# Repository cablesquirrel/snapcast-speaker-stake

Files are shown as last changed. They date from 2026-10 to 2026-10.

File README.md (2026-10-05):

# Snapcast Speaker Stake

Hardware and firmware design to retrofit the [Hampton Bay B0029RA](https://www.homedepot.com/p/Hampton-Bay-16-9-in-Black-Outdoor-Landscape-Speaker-B0029RA-2/305754399) outdoor Bluetooth speaker into a [Snapcast](https://github.com/snapcast/snapcast) client.

The design uses an [ESP32-S3 (Seeed XIAO)](https://www.seeedstudio.com/XIAO-ESP32S3-p-5627.html) along with a [I2S DAC](https://www.amazon.com/dp/B08YNJGSN4) and [5-watt amplifier](https://www.amazon.com/dp/B0F6YBYMWY).

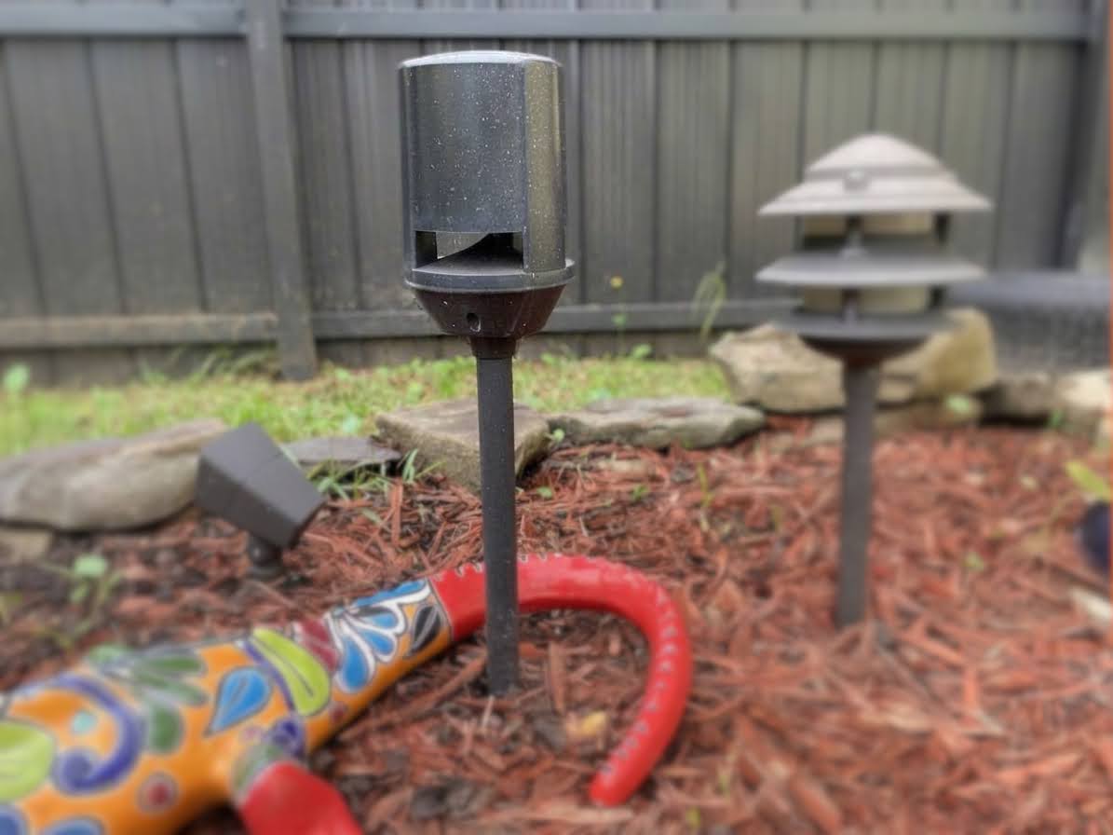
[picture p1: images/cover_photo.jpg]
Cover Photo


## 📁 Repo Layout

```
hardware/
  LICENSE          CERN-OHL-S-2.0
  libraries/       Footprint and symbol libraries used by both boards
  v1/              KiCad project and Gerbers, original 3 W design (MAX98357A)
  v2.0.1/          KiCad project and Gerbers, 5 W design (GY-PCM5102A + CH05D)
firmware/
  snapclient/      Upstream firmware (submodule, pinned to 5cda3a7)
  patches/         upstream-changes.patch: our changes to four upstream files
  overlay/         New files we add (status_led component, speaker-stake sdkconfigs)
  CHANGES.md       Every file and line changed from upstream, with rationale
scripts/
  setup-firmware.ps1  Applies the patch and overlay to firmware/snapclient
releases/
  max98357_combo/  Prebuilt flash images for the 3 W flavor
  pcm5102a_ch05d/  Prebuilt flash images for the 5 W flavor
```

## 💿 Firmware flavors

| Flavor | Hardware | Config | Release |
|---|---|---|---|
| 3 W combo | XIAO + MAX98357A | `firmware/overlay/sdkconfig.max98357_combo` | `releases/max98357_combo/` |
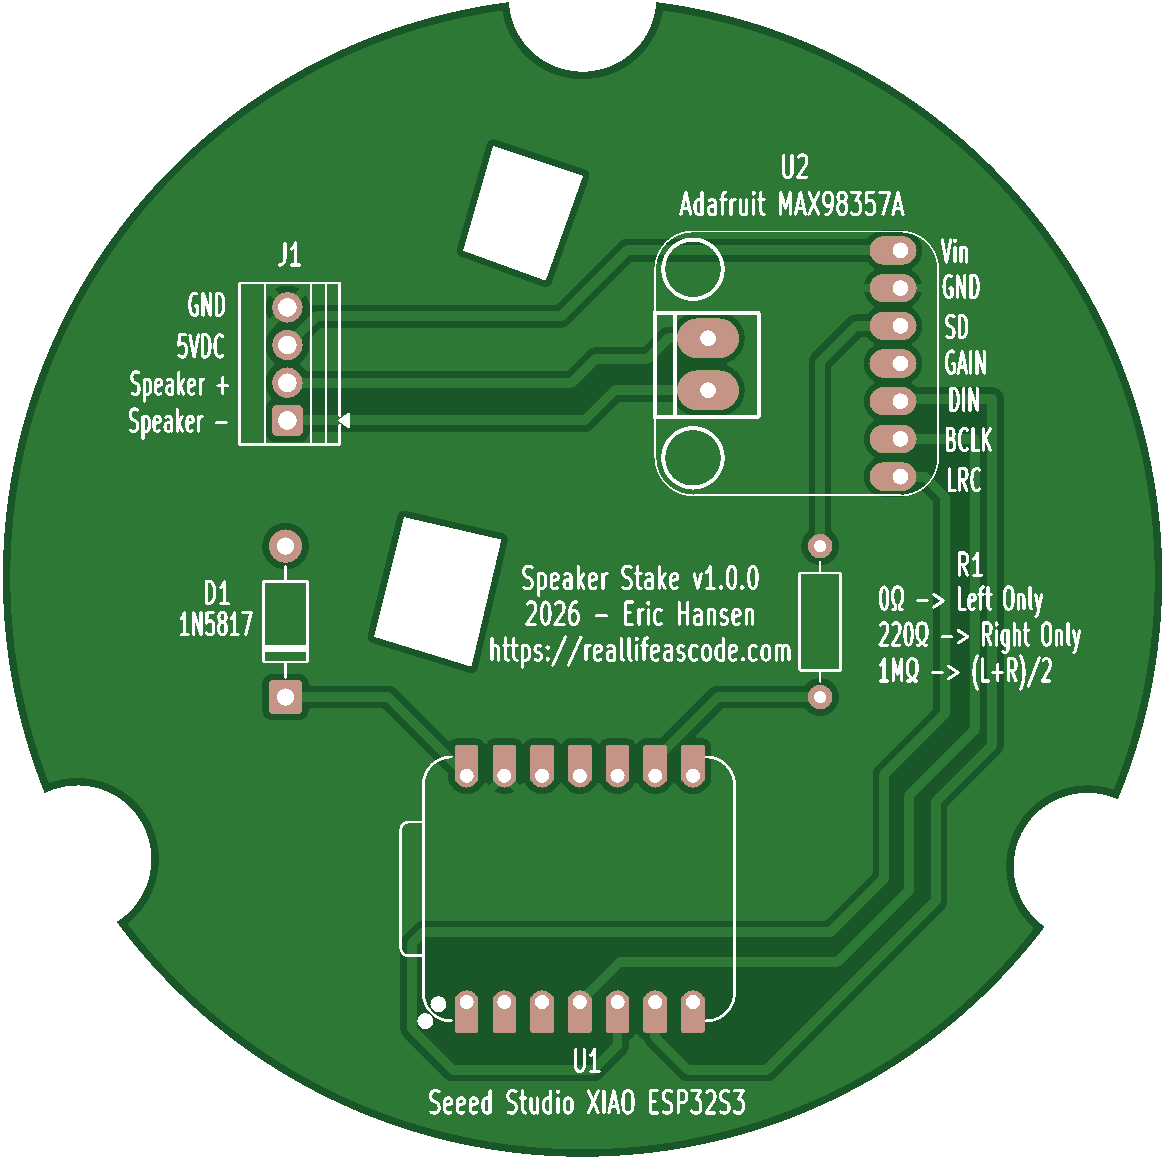
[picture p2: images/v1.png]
v1 image
|  | | | |
| 5 W separate | XIAO + GY-PCM5102A + CH05D | `firmware/overlay/sdkconfig.pcm5102a_ch05d` | `releases/pcm5102a_ch05d/` |
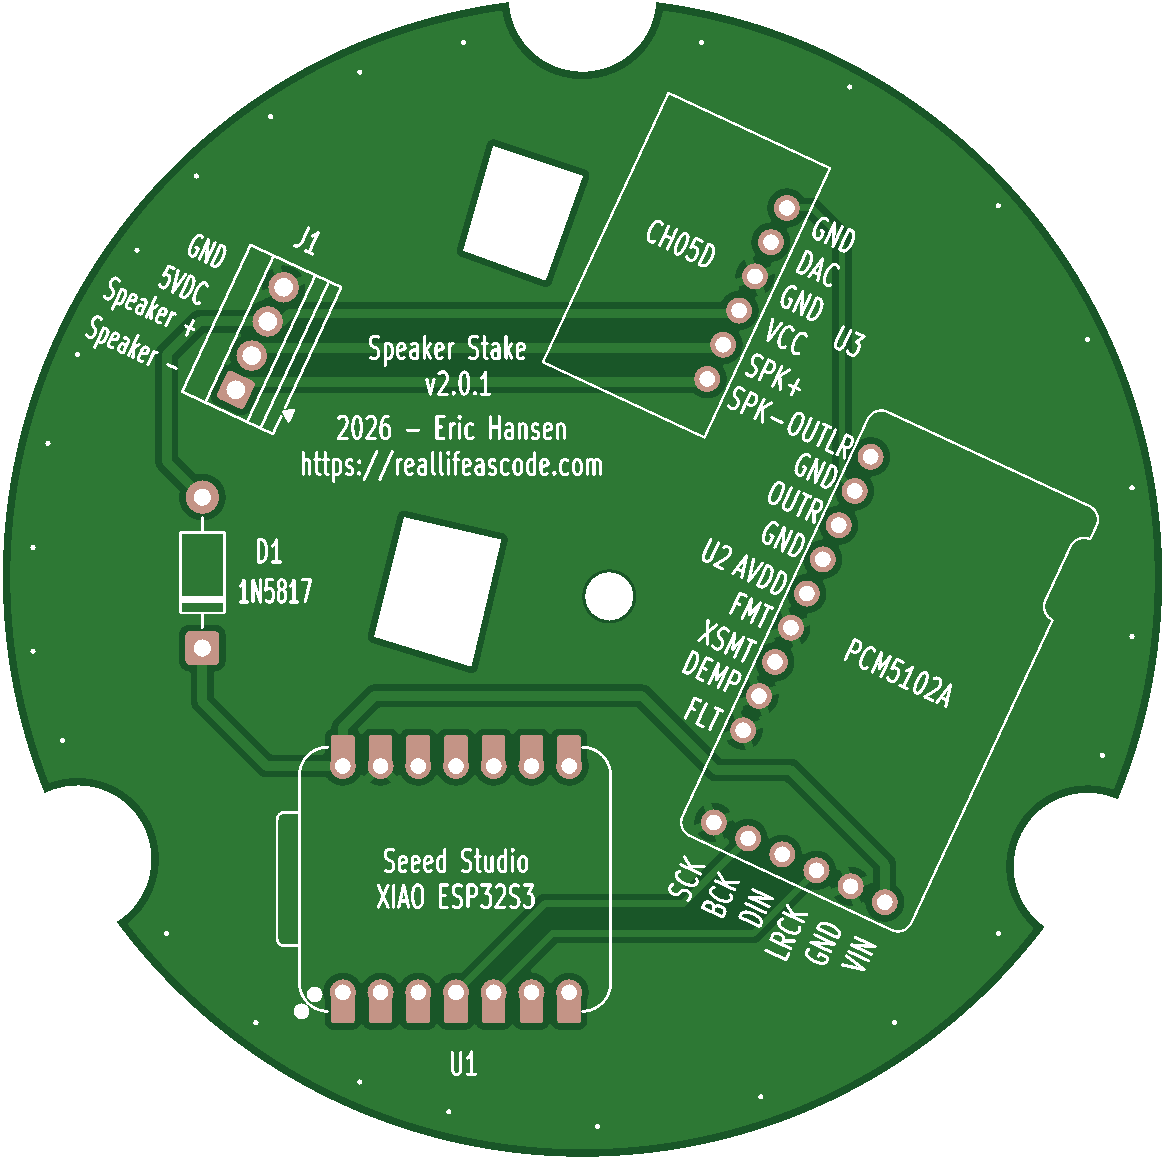
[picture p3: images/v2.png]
v2 image
|  | | | |

Both flavors are built from the same source tree. They differ only in DAC configuration. See `firmware/CHANGES.md` for the full list of changes from upstream.

## 📦 Flash a prebuilt release

Each release folder contains the four images needed for a full flash:

```
python -m esptool --chip esp32s3 -p COMx write_flash \
  0x0 bootloader.bin 0x8000 partition-table.bin 0x1d000 ota_data_initial.bin 0x20000 snapclient.bin
```

Replace `COMx` with the board's port. Run this from inside the release folder.

## 🛠 Set up ESP-IDF (Windows)

The firmware builds with ESP-IDF **v5.5.1**. Other versions are untested.

1. **Install Git for Windows** from https://git-scm.com/download/win if you don't have it.

2. **Clone ESP-IDF v5.5.1 with submodules.** This takes a while. In PowerShell:
   ```powershell
   mkdir C:\Espressif
   cd C:\Espressif
   git clone -b v5.5.1 --recursive https://github.com/espressif/esp-idf.git
   ```

3. **Install the toolchain for the ESP32-S3:**
   ```powershell
   cd C:\Espressif\esp-idf
   .\install.ps1 esp32s3
   ```
   This downloads the Xtensa compiler, CMake, Ninja, and a Python virtual environment. By default they go under `%USERPROFILE%\.espressif`. To put them elsewhere, set `IDF_TOOLS_PATH` before running the script, for example `$env:IDF_TOOLS_PATH = "C:\Espressif\tools"`.

   If PowerShell blocks the script, run `Set-ExecutionPolicy -Scope CurrentUser RemoteSigned` once and try again.

4. **Activate the environment in every new terminal.** From the `esp-idf` folder:
   ```powershell
   .\export.ps1
   ```
   If you set `IDF_TOOLS_PATH` in step 3, set it again in the terminal first.

5. **Check the install:**
   ```powershell
   idf.py --version
   ```
   It should print `ESP-IDF v5.5.1`.

6. **Connect the board.** The XIAO ESP32-S3 uses its built-in USB-C port, so no USB-serial driver is needed. If no COM port appears, try a different cable. Some cables only charge and don't carry data.

When `idf.py --version` works, continue to **Build from source** below.

## 📚 Build from source

First, clone the repo with its submodules and prepare the firmware. This only needs to be done once per clone:

```powershell
git clone --recursive https://github.com/cablesquirrel/snapcast-speaker-stake
cd snapcast-speaker-stake
.\scripts\setup-firmware.ps1
```

The script checks out upstream at the pinned commit, applies `firmware/patches/upstream-changes.patch`, and copies in the overlay files. It is safe to run again.

Requires ESP-IDF 5.5.1 (see above). Build each flavor from `firmware/snapclient` into its own directory:

```
cd firmware\snapclient
idf.py -B build -D SDKCONFIG=sdkconfig.max98357_combo build
idf.py -B build.pcm5102a_ch05d -D SDKCONFIG=sdkconfig.pcm5102a_ch05d build
```

## 📶 OTA update

With the device on the network, push a new app image to its OTA listener on port 8032. Use a direct file reference so curl sends a Content-Length header:

```
curl <device-ip>:8032 --data-binary @releases/pcm5102a_ch05d/snapclient.bin
```

The connection is reset when the transfer completes. That is expected: the device reboots into the new image.

## 📱 WiFi

WiFi credentials are not compiled in. Provision them over USB-C with Improv WiFi (for example, web.esphome.io).

## 📝 Hardware notes

- Footprint and symbol libraries used by the boards are in `hardware/libraries/`. Each project's `fp-lib-table` and `sym-lib-table` reference them with `${KIPRJMOD}/../libraries/`, so the projects open from a fresh clone. Add the libraries to your global KiCad tables only if you need them outside these projects.
- `hardware/libraries/` contains the Seeed XIAO series, GY-PCM5102A, CH05D (provisional, see its KNOWN_ISSUES), and Adafruit MAX98357A libraries as copied from the local KiCad setup.
- The V2.0.1 known issues are listed in `hardware/v2.0.1/KNOWN_ISSUES.md`. That board was sent to fab with them.

## ⚖ Licensing

- **Hardware** (`hardware/`): [CERN-OHL-S-2.0](hardware/LICENSE), the strongly reciprocal open-source hardware license. The GY-PCM5102A footprint in this project derives from a CERN-OHL-S library, and that license requires derivatives to stay under the same terms.
- **Firmware** (`firmware/`): upstream [CarlosDerSeher/snapclient](https://github.com/CarlosDerSeher/snapclient) is pulled in as a submodule under GPL-3.0 (see `firmware/snapclient/LICENSE`). Our changes are listed in `firmware/CHANGES.md`. Because they modify GPL-3.0 code, they are also GPL-3.0. The firmware overlay files (`status_led` and the sdkconfigs) are included in that same GPL-3.0 grant.
- **Third-party libraries**: the Adafruit MAX98357A library (`adafruit-MAX98357.*`) comes from [besi/kicad-adafruit-MAX98357](https://github.com/besi/kicad-adafruit-MAX98357), and the Seeed XIAO library (`Seeed_Studio_XIAO_Series.*`) comes from Seeed Studio. The Seeed library is CC-BY-SA-4.0 (see `hardware/libraries/LICENSES/`). The Adafruit library has no declared license upstream and is included as-is, pending a takedown request if the owner objects. See `hardware/libraries/README.md`.

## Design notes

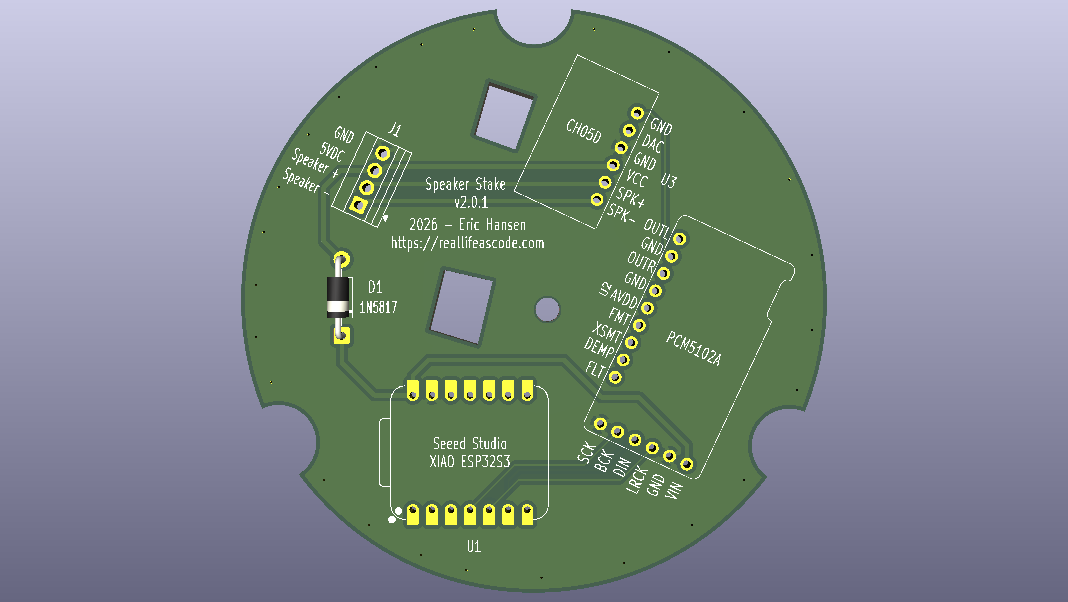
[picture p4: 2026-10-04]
hardware/v2.0.1/Speaker_Stake_v2.0.1.png

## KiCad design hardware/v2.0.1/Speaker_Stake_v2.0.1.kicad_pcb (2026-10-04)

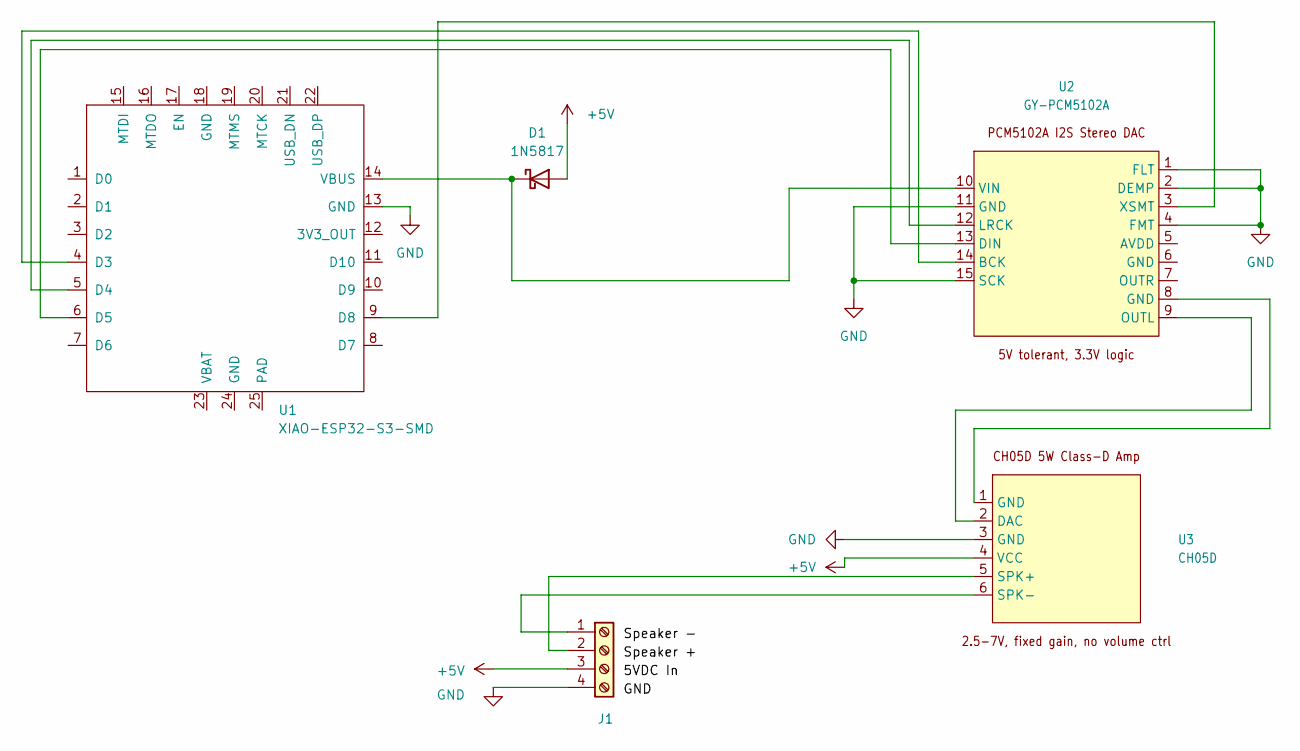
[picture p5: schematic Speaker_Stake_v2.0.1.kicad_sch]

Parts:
D1: 1N5817; D_DO-41_SOD81_P10.16mm_Horizontal
J1: Screw_Terminal_01x04; TerminalBlock_Xinya_XY308-2.54-4P_1x04_P2.54mm_Horizontal
U1: XIAO-ESP32-S3-SMD; XIAO-ESP32-S3-DIP
U2: GY-PCM5102A
U3: CH05D

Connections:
+5V: D1.2 (A), J1.3, U3.4 (VCC)
GND: J1.4, U1.13 (GND), U2.1 (FLT), U2.2 (DEMP), U2.4 (FMT), U2.11 (GND), U2.15 (SCK), U3.3 (GND)
unnamed: D1.1 (K), U1.14 (VBUS), U2.10 (VIN)
unnamed: J1.1, U3.6 (SPK-)
unnamed: J1.2, U3.5 (SPK+)
unnamed: U1.4 (D3), U2.14 (BCK)
unnamed: U1.5 (D4), U2.12 (LRCK)
unnamed: U1.6 (D5), U2.13 (DIN)
unnamed: U1.9 (D8), U2.3 (XSMT)
unnamed: U2.8 (GND), U3.1 (GND)
unnamed: U2.9 (OUTL), U3.2 (DAC)

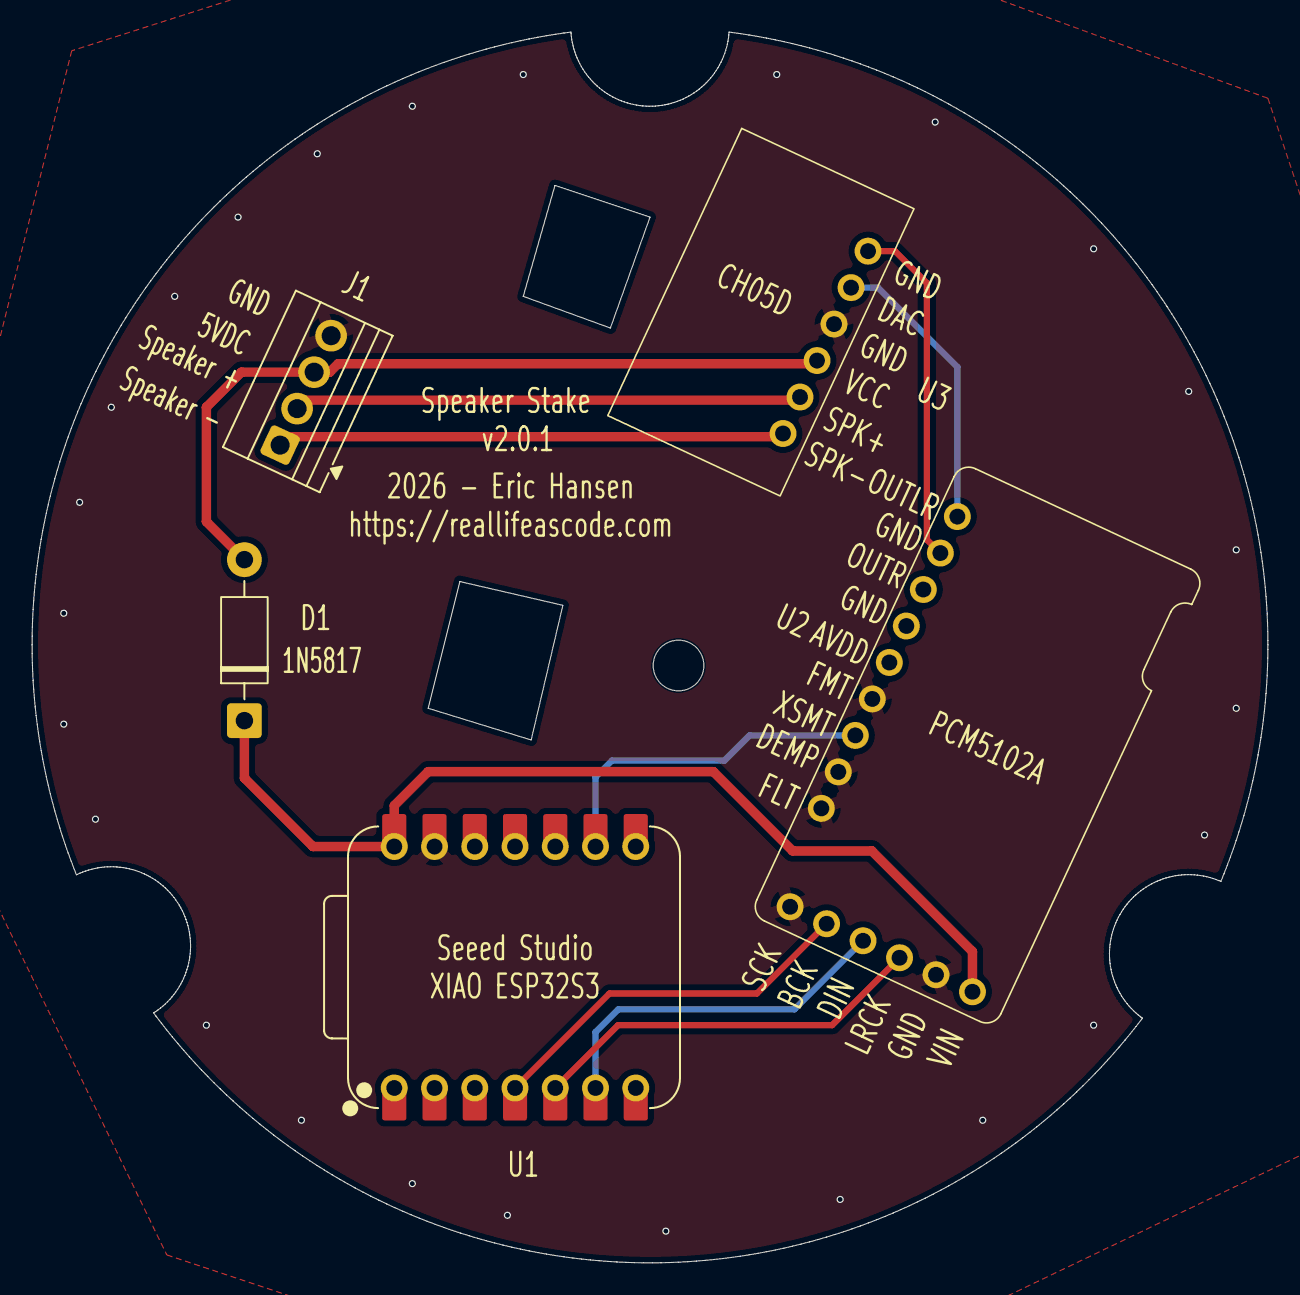
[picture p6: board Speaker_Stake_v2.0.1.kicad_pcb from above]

Board: 2 copper layers, 78.0 x 77.7 mm, 5 parts (0 on the bottom side), 11 nets.

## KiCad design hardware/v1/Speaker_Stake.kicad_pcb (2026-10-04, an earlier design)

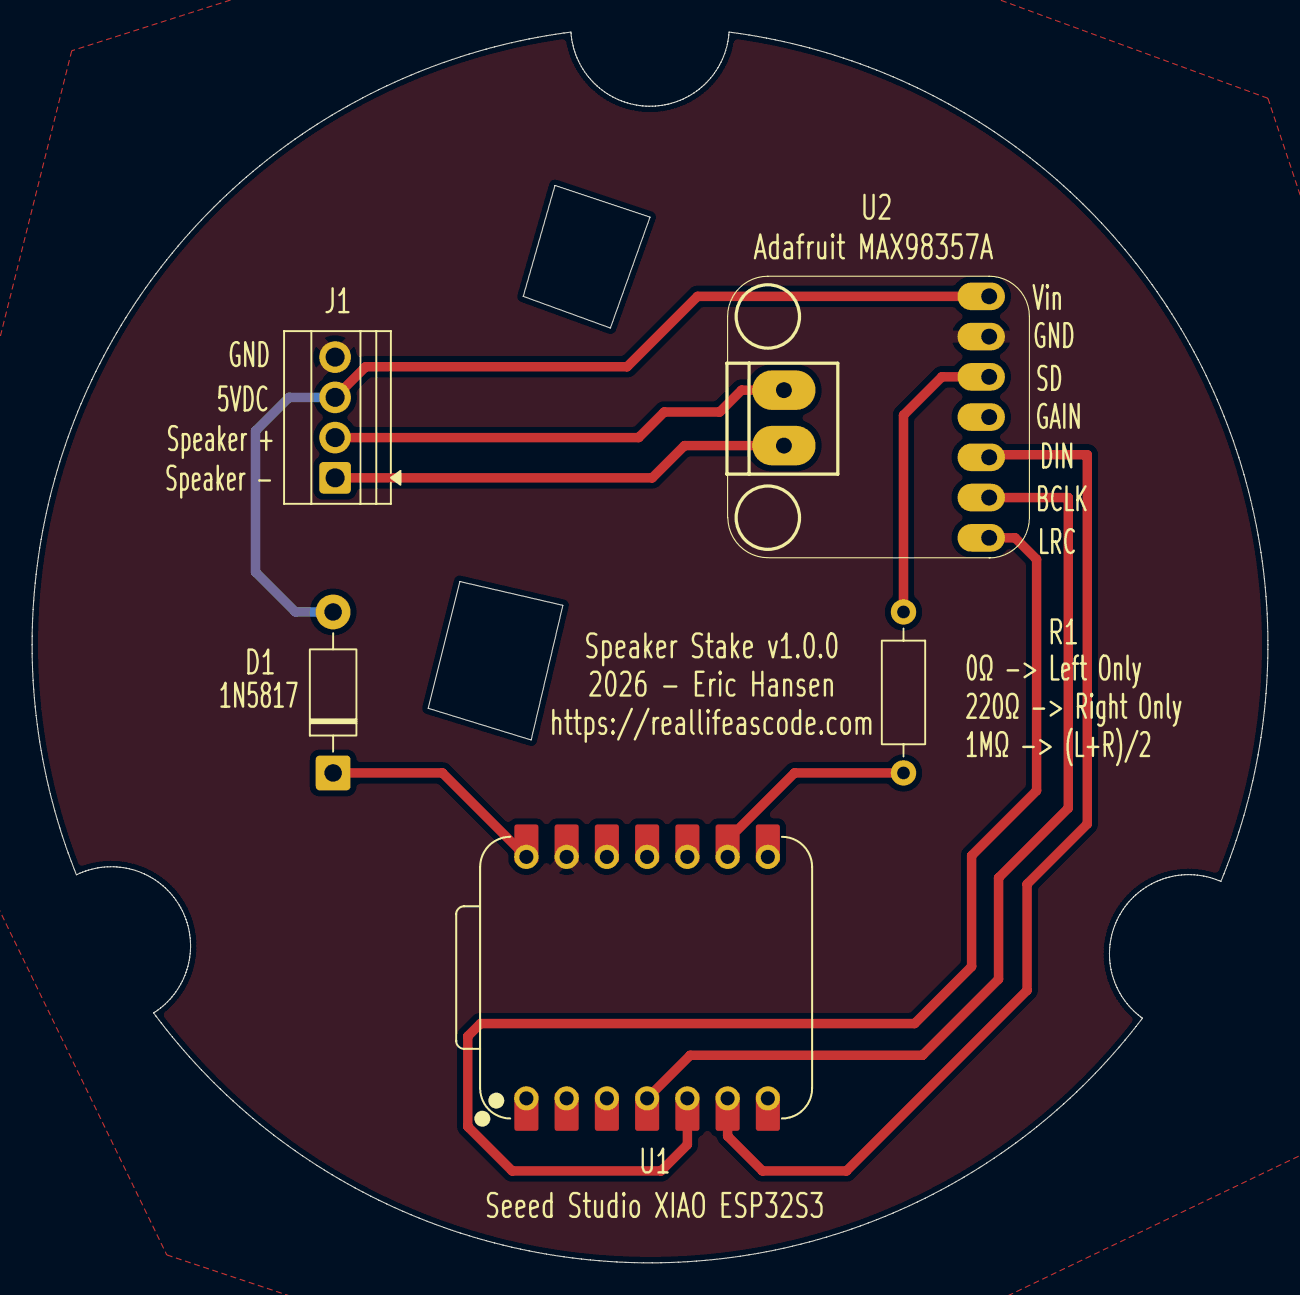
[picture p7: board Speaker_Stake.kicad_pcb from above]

Board: 2 copper layers, 78.0 x 77.7 mm, 5 parts (0 on the bottom side), 10 nets.

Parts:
D1: 1N5817; D_DO-41_SOD81_P10.16mm_Horizontal
J1: Screw_Terminal_01x04; TerminalBlock_Xinya_XY308-2.54-4P_1x04_P2.54mm_Horizontal
R1: 1M; R_Axial_DIN0207_L6.3mm_D2.5mm_P10.16mm_Horizontal
U1: XIAO-ESP32-S3-SMD; XIAO-ESP32-S3-DIP
U2: adafruit-MAX98357

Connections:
+5V: D1.2 (A), J1.3, U2.1 (Vin)
GND: J1.4, U1.13 (GND), U2.2 (GND)
unnamed: D1.1 (K), U1.14 (VBUS)
unnamed: J1.1, U2.8 (OUTP)
unnamed: J1.2, U2.9 (OUTN)
unnamed: U1.4 (D3), U2.6 (BCLK)
unnamed: U1.5 (D4), U2.7 (LRC)
unnamed: U1.6 (D5), U2.5 (DIN)
unnamed: R1.2, U1.9 (D8)
unnamed: R1.1, U2.3 (~SD_MODE)

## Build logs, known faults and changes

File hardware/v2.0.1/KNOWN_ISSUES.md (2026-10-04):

# V2.0.1 known issues

## Open

1. **CH05D pin header is mirrored.** The CH05D footprint has its pins in the reverse left-right order from the real module. The footprint came from a provisional library part built from a product photo (`kicad-lib-CH05D`), not from verified dimensions. Workaround for the boards already built: solder the module upside down, with the chip facing the carrier board. Check clearance before soldering. Confirm the actual pin order on a physical module before fixing the footprint in the next revision.

## Resolved in the final design

- **FLT, DEMP, and FMT floating.** These pins were left unconnected on the breadboard, where they caused crackling and popping. The final design ties them to GND.
- **CH05D VCC on the diode-protected rail.** The amplifier's VCC was fed through the reverse-protection diode, which drops voltage under load. The final design feeds it from the raw +5 V net.

> **Note:** AVDD on the GY-PCM5102A header is unconnected on purpose. It is an output of the module's onboard LDO, fed from VIN, not an input. Leave it unconnected.

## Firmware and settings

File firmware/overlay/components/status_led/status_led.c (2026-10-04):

#include "status_led.h"

#include "sdkconfig.h"

#if CONFIG_STATUS_LED_ENABLE

#include "driver/gpio.h"
#include "esp_log.h"
#include "freertos/FreeRTOS.h"
#include "freertos/task.h"

static const char *TAG = "STATUS_LED";

static volatile status_led_state_t s_state = STATUS_LED_STATE_CONNECTING;

#if CONFIG_STATUS_LED_ACTIVE_LOW
#define LED_ON_LEVEL 0
#define LED_OFF_LEVEL 1
#else
#define LED_ON_LEVEL 1
#define LED_OFF_LEVEL 0
#endif

static void status_led_task(void *pv) {
  (void)pv;
  bool on = false;

  while (1) {
    switch (s_state) {
      case STATUS_LED_STATE_READY:
        gpio_set_level(CONFIG_STATUS_LED_GPIO, LED_ON_LEVEL);
        vTaskDelay(pdMS_TO_TICKS(200));
        break;

      case STATUS_LED_STATE_WAITING:
        on = !on;
        gpio_set_level(CONFIG_STATUS_LED_GPIO, on ? LED_ON_LEVEL : LED_OFF_LEVEL);
        vTaskDelay(pdMS_TO_TICKS(600));
        break;

      case STATUS_LED_STATE_CONNECTING:
      default:
        on = !on;
        gpio_set_level(CONFIG_STATUS_LED_GPIO, on ? LED_ON_LEVEL : LED_OFF_LEVEL);
        vTaskDelay(pdMS_TO_TICKS(150));
        break;
    }
  }
}

void status_led_init(void) {
  gpio_reset_pin(CONFIG_STATUS_LED_GPIO);
  gpio_set_direction(CONFIG_STATUS_LED_GPIO, GPIO_MODE_OUTPUT);
  gpio_set_level(CONFIG_STATUS_LED_GPIO, LED_OFF_LEVEL);

  BaseType_t r = xTaskCreate(status_led_task, "status_led", 2048, NULL,
                             tskIDLE_PRIORITY + 1, NULL);
  if (r != pdPASS) {
    ESP_LOGW(TAG, "failed to create status_led task");
  }
}

void status_led_set_state(status_led_state_t state) { s_state = state; }

#else  // !CONFIG_STATUS_LED_ENABLE

void status_led_init(void) {}
void status_led_set_state(status_led_state_t state) { (void)state; }

#endif

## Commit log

2026-10-04 Organize hardware, firmware, and releases for the speaker stake
    hardware/: KiCad projects and Gerbers for V1 (3 W, MAX98357A) and
    V2.0.1 (5 W, GY-PCM5102A + CH05D), with V2.0.1 known issues.
    firmware/: upstream snapclient source with local changes. Every changed
    file and line is documented in firmware/CHANGES.md and reproduced as
    firmware/patches/upstream-changes.patch (applies cleanly to 5cda3a7).
    releases/: prebuilt flash images for both XIAO flavors.
    Claude-Session: https://claude.ai/code/session_01YaBtJmhaXcta9Mx1K4pLMU
    [Speaker_Stake-B_Mask.gbs, Speaker_Stake-B_Paste.gbp, Speaker_Stake-B_Silkscreen.gbo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]
2026-10-04 Clean up firmware, add hardware libraries, and set hardware license
    - Remove the OTA receive-loop watchdog yield (wrong diagnosis; the real
    OTA fix is the 8 KB task stack in main/main.c). ota_server.c now
    matches upstream.
    - Restore the flac build makefiles that were accidentally deleted in the
    submodule working copy.
    - Add hardware/libraries/ with the footprint and symbol libraries used
    by both board projects, and point each project's fp-lib-table and
    sym-lib-table at them with ${KIPRJMOD}-relative paths.
    - Release the hardware under CERN-OHL-S-2.0.
    - Rebuild release images from the cleaned source.
    Claude-Session: https://cl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
2026-10-04 Re-upload gerber files as a RAR archive
2026-10-04 Update V2.0.1 known issues after bring-up on the final PCB
    FLT/DEMP/FMT ground ties and CH05D VCC routing are fixed in the final
    design. Audio and power grounds stay separate by design. Antenna noise
    was a breadboard-only issue. Only the mirrored CH05D header remains open.
    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
2026-10-04 Use upstream snapclient as a submodule with patch and overlay
    firmware/snapclient is upstream at 5cda3a7 (GPL-3.0), with no local
    edits in its tree. Our changes are in firmware/patches/ (four modified
    files) and firmware/overlay/ (new files). scripts/setup-firmware.ps1
    applies them after a recursive submodule clone.
    The vendored copy is kept on the local vendored-v1 branch.
    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
    [partitions.csv]
2026-10-04 Pin managed component versions in the firmware overlay
    Upstream gitignores dependencies.lock, so fresh clones resolved newer
    managed components (for example espressif/mdns) than the firmware was
    built and tested with. Keep the tested lock in firmware/overlay and have
    setup-firmware.ps1 copy it in.
    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
